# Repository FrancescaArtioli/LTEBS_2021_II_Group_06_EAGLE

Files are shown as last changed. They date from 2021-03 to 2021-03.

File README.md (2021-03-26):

# LTEBS_2021_II_Group_06_EAGLE
Authors: Artioli Francesca, Parrella Giovanni

This repository contains a complete Eagle project of a custom PCB, designed in order to ease the assessment of the performance of the PSoC-5LP microcontroller. 
In particular, the repository contains the schematic (.sch), the board (.brd) and the design-rule-check file (.dru) based on technical requirements by MDSrl. 

The PCB embeds the developement kit for PSoC-5LP (namely CY8CKIT-059_TARGET) together with sensors and additional components required to conduct the proper testing.

### Sensors (from SparkFun-Sensors.lbr) 
-	Light Sensor

	PHOTOCELLPTH - PHOTOCELL

- 	Analog Temperature Sensor

	TMP36GT9 - TO-92
  
### Libraries 

- SparkFun-Eagle-Libraries, downloaded from https://github.com/sparkfun/SparkFun-Eagle-Libraries

- CY8KIT-059.lbr, downloaded from https://github.com/dado93/Cypress-Eagle

- Group_06_Library.lbr, a custom library for TMUX1208 and TCA9546A from Texas Instruments.

### Notes on Group_06_Library.lbr
-	We have decided to design the pads for both components TMUX1208 (package QFN-16) and TCA9546A (package TSSOP-16) with a rectangular shape. 
-	Regarding package dimension of component TMUX1208 we have decided to keep the middle value between maximum and minimum dimension (1.80mmx2.60mm).
-	Regarding package dimension of component TCA9546A we have decided to keep the middle value between maximum and minimum dimension (4.4mmx5mm).
-	In both the components' footprint we have added the profile silkscreen in a way that it wouldn't provide a stop-mask error in the DRC (even if we have not considered stop mask error when running the DRC file, as suggested). 

### Notes on Group_06.sch 
-	Schematic is divided into two pages.

### Notes on Group_06.brd
-	The trace dimension was set to 10 mils for all traces of the PCB, except for those connecting to the mux which were set to 8 mils to avoid clearance errors.
-	Final board dimensions are : 60.83 mm x 72.39 mm

### Notes on Group_06.dru
-	We followed the requirements from the MDSrl.
-	The "check stop mask" option in the MISC section was not selected, as suggested.

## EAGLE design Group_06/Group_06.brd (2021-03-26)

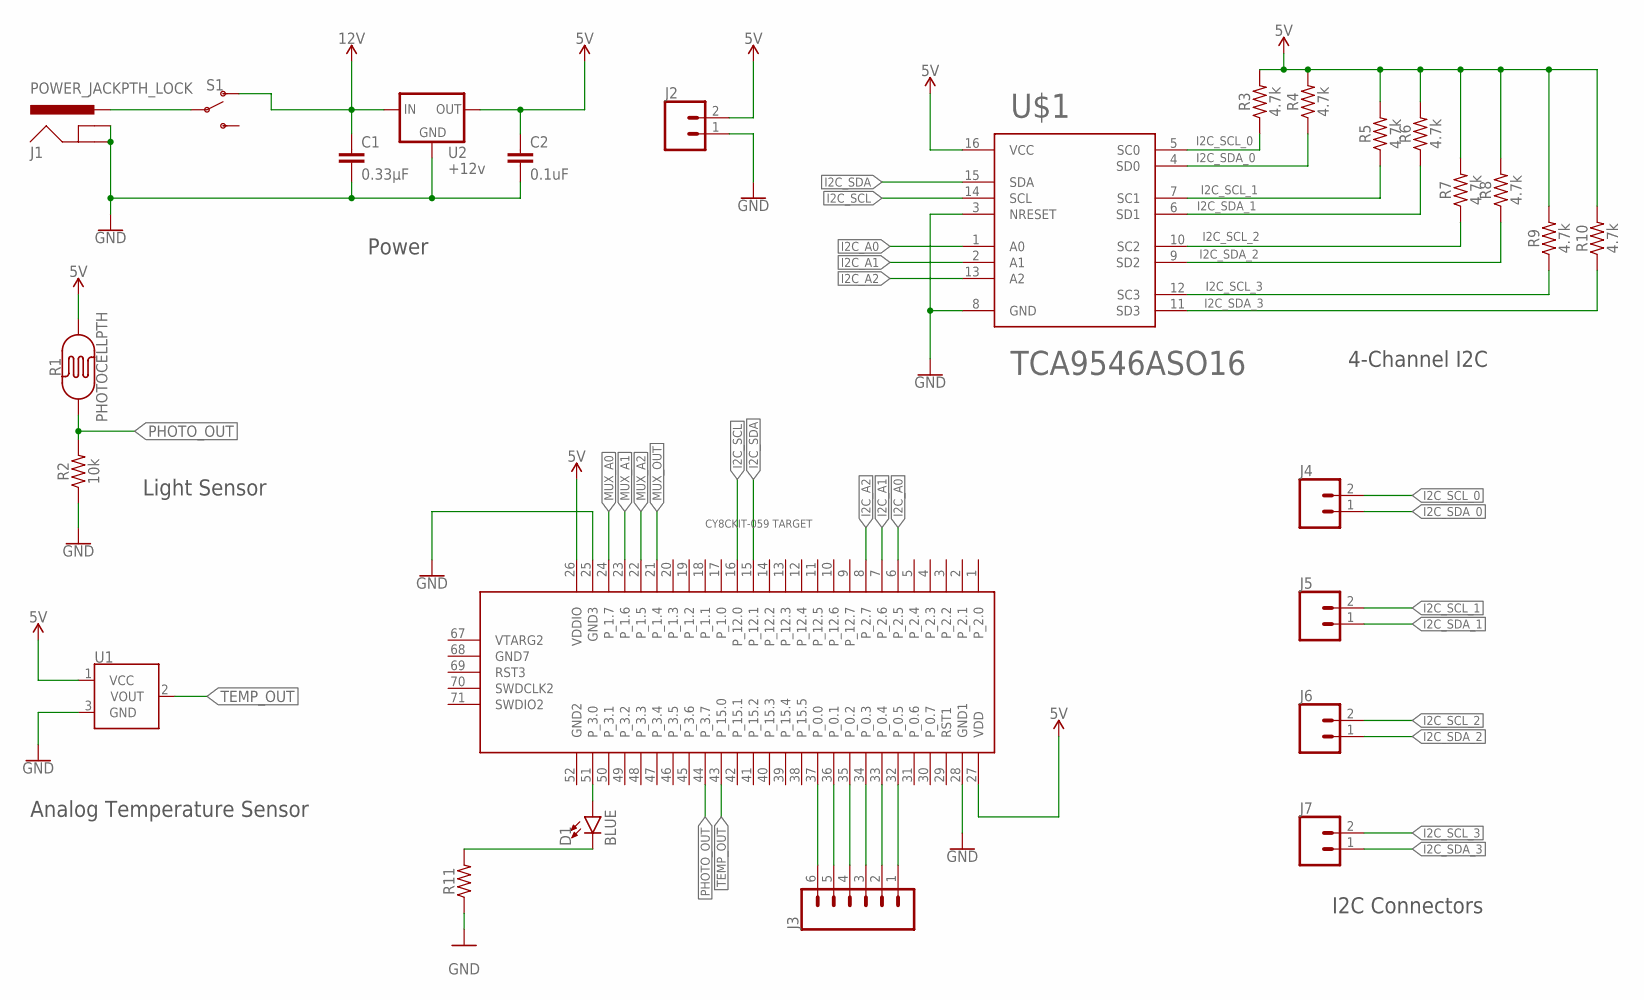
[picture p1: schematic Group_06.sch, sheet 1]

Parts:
C1: 0.33µF; 0805
C2: 0.1uF; CAP-PTH-SMALL-KIT
D1: BLUE; LED-1206
J1: POWER_JACKPTH_LOCK; POWER_JACK_PTH_LOCK
J2, J4, J5, J6, J7: CONN_02; 1X02
J3: CONN_06LOCK; 1X06_LOCK
R1: PHOTOCELLPTH; PHOTOCELL
R2: 10k; 0603
R3, R4, R5, R6, R7, R8, R9, R10: 4.7k; 0603
R11: AXIAL-0.3
S1: SWITCH-SPDT-PTH-11.6X4.0MM; SWITCH_SPDT_PTH_11.6X4.0MM
U1: TMP36GT9; TO-92
U2: +12v; TO-252
U$1: TCA9546ASO16; TSSOP-16
U$2: CY8CKIT-059_TARGET

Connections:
5V: C2.1, J2.2, R1.2, R3.2, R4.2, R5.2, R6.2, R7.2, R8.2, R9.2, R10.2, U1.1 (VCC), U2.2 (OUT), U$1.16 (VCC), U$2.26 (VDDIO), U$2.27 (VDD); also elsewhere on the board
12V: C1.1, S1.1 (O), U2.1 (IN)
GND: C1.2, C2.2, J1.GND, J1.GNDBREAK, J2.1, R2.1, R11.P$1 (1), U1.3 (GND), U2.3 (GND), U$1.3 (NRESET), U$1.8 (GND), U$2.25 (GND3), U$2.28 (GND1); also elsewhere on the board
I2C_A0: U$1.1 (A0), U$2.6 (P_2.5)
I2C_A1: U$1.2 (A1), U$2.7 (P_2.6)
I2C_A2: U$1.13 (A2), U$2.8 (P_2.7)
I2C_SCL: U$1.14 (SCL), U$2.16 (P_12.0)
I2C_SCL_0: J4.2, R3.1, U$1.5 (SC0)
I2C_SCL_1: J5.2, R5.1, U$1.7 (SC1)
I2C_SCL_2: J6.2, R7.1, U$1.10 (SC2)
I2C_SCL_3: J7.2, R9.1, U$1.12 (SC3)
I2C_SDA: U$1.15 (SDA), U$2.15 (P_12.1)
I2C_SDA_0: J4.1, R4.1, U$1.4 (SD0)
I2C_SDA_1: J5.1, R6.1, U$1.6 (SD1)
I2C_SDA_2: J6.1, R8.1, U$1.9 (SD2)
I2C_SDA_3: J7.1, R10.1, U$1.11 (SD3)
MUX_A0: U$2.24 (P_1.7); also elsewhere on the board
MUX_A1: U$2.23 (P_1.6); also elsewhere on the board
MUX_A2: U$2.22 (P_1.5); also elsewhere on the board
MUX_OUT: U$2.21 (P_1.4); also elsewhere on the board
unnamed: J1.PWR, S1.2
unnamed: D1.A, U$2.51 (P_3.0)
unnamed: D1.C, R11.P$2 (2)
unnamed: J3.6, U$2.37 (P_0.0)
unnamed: J3.5, U$2.36 (P_0.1)
unnamed: J3.4, U$2.35 (P_0.2)
unnamed: J3.3, U$2.34 (P_0.3)
unnamed: J3.2, U$2.33 (P_0.4)
unnamed: J3.1, U$2.32 (P_0.5)
PHOTO_OUT: R1.1, R2.2, U$2.44 (P_3.7)
TEMP_OUT: U1.2 (VOUT), U$2.43 (P_15.0)

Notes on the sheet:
I2C Connectors
4-Channel I2C
Power
Light Sensor
Analog Temperature Sensor

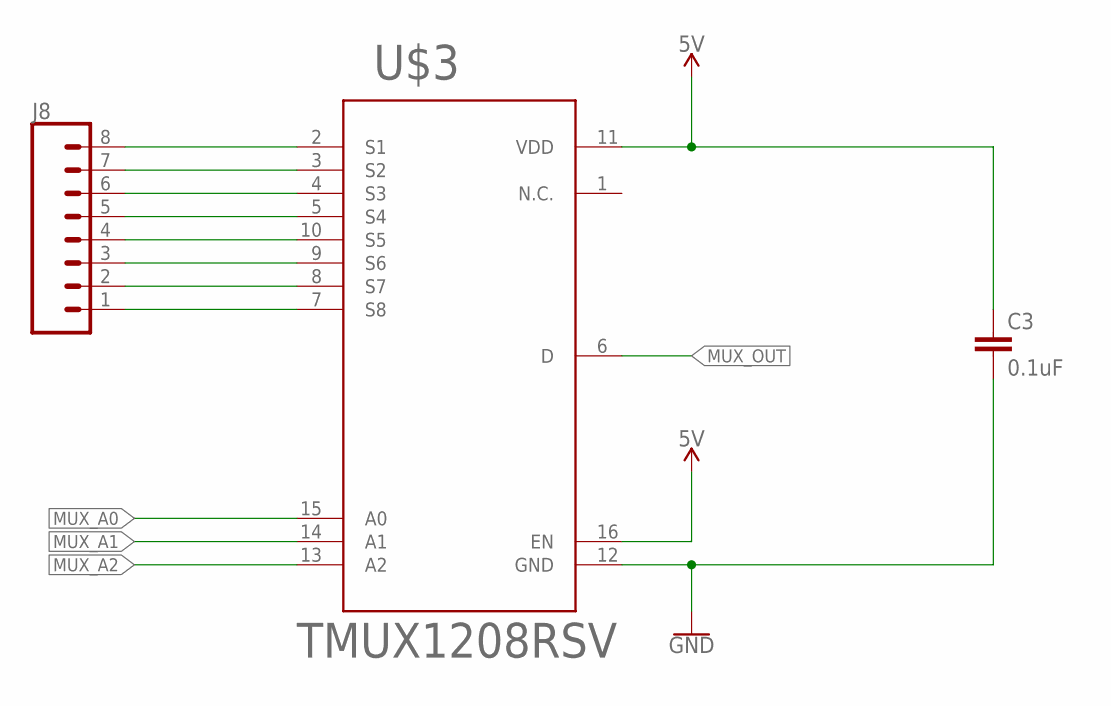
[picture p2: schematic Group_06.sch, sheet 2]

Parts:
C3: 0.1uF; CAP-PTH-SMALL-KIT
J8: CONN_08LOCK; 1X08_LOCK
U$3: TMUX1208RSV; QFN-16

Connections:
5V: C3.1, U$3.11 (VDD), U$3.16 (EN); also elsewhere on the board
GND: C3.2, U$3.12 (GND); also elsewhere on the board
MUX_A0: U$3.15 (A0); also elsewhere on the board
MUX_A1: U$3.14 (A1); also elsewhere on the board
MUX_A2: U$3.13 (A2); also elsewhere on the board
MUX_OUT: U$3.6 (D); also elsewhere on the board
unnamed: J8.8, U$3.2 (S1)
unnamed: J8.7, U$3.3 (S2)
unnamed: J8.6, U$3.4 (S3)
unnamed: J8.5, U$3.5 (S4)
unnamed: J8.4, U$3.10 (S5)
unnamed: J8.3, U$3.9 (S6)
unnamed: J8.2, U$3.8 (S7)
unnamed: J8.1, U$3.7 (S8)

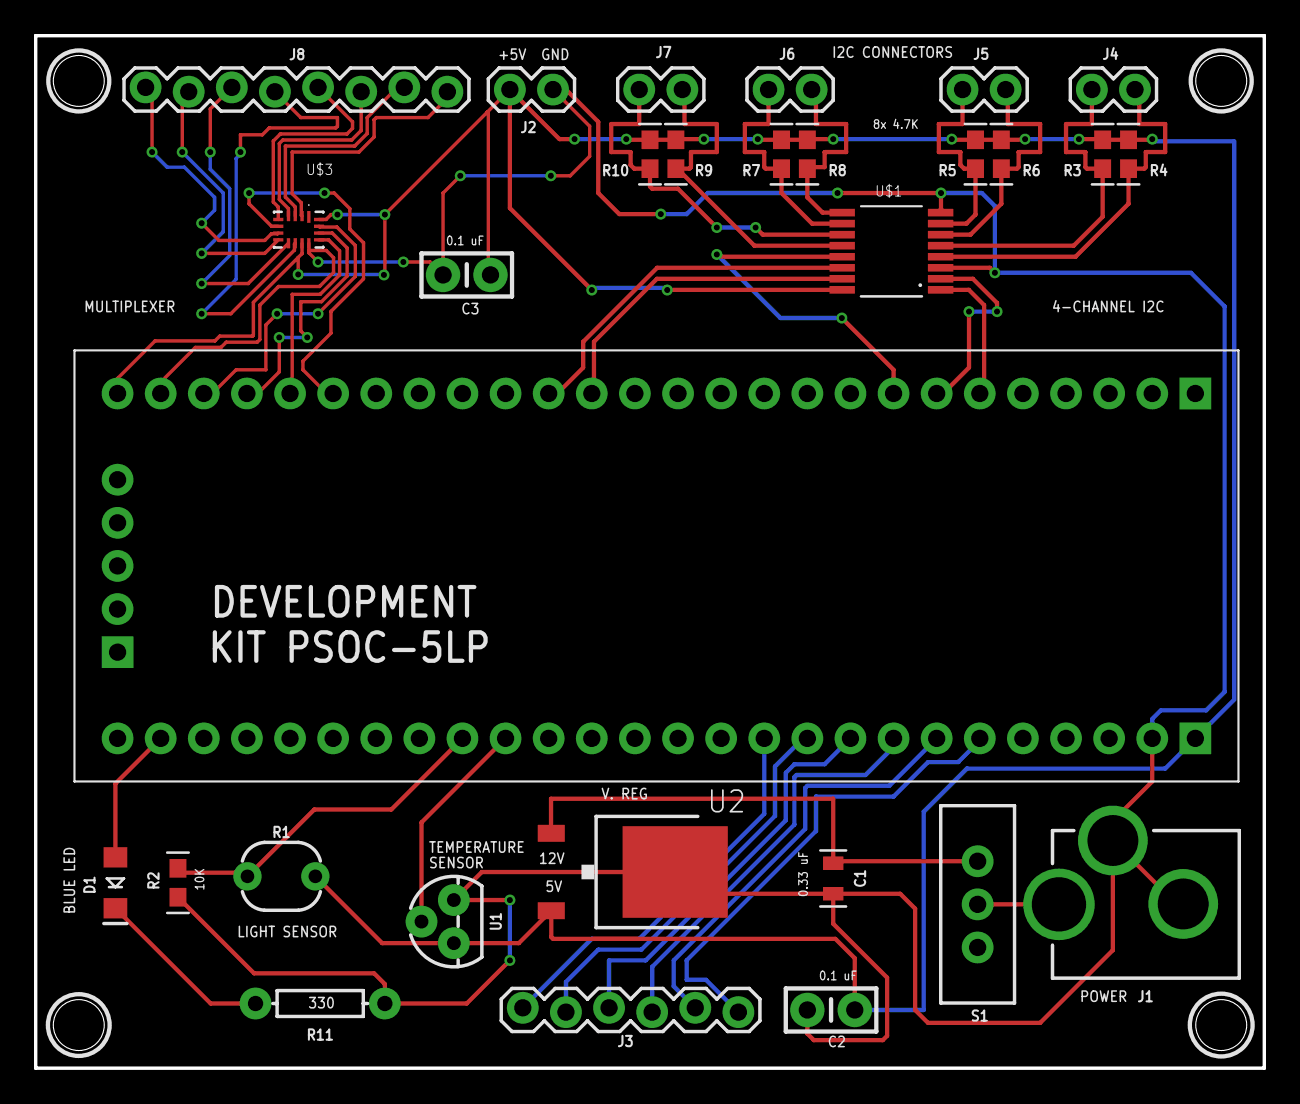
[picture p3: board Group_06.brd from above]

Board: 2 copper layers, 72.4 x 60.8 mm, 29 parts (0 on the bottom side), 39 nets.

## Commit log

2021-03-18 Sch_5components and variant name
    [Group_06.brd, Group_06.sch]
2021-03-19 I2C_Connectors and Names
    [Group_06.brd, Group_06.sch]
2021-03-19 Adding TMUX1208
    [Group_06.brd, Group_06.sch]
2021-03-19 Change microcontroller and fixing connection problem
    [Group_06.brd, Group_06.sch]
2021-03-19 first try board
    [Group_06.brd]
2021-03-20 Board Layout 1
    [Group_06.brd]
2021-03-20 Board Layout 2
    [Group_06.brd]
2021-03-20 Board Layout 3
    [Group_06.brd]
2021-03-20 Routing 1
    [Group_06.brd]
2021-03-20 Routing 2
    [Group_06.brd]
2021-03-22 Dev mux fra (#1)
    * MUX 1
    * Routing optimization and correct placing tNames
    [Group_06.brd]
2021-03-22 Silkscreen (#4)
    * update DRC file
    * Silkscreen labels and fixing stop mask interferences
    * update silkscreen and fix library problem
    [Group_06.brd]
2021-03-22 fixing power and silkscreen (#5)
    [Group_06.brd]
2021-03-23 Dev corrections (#6)
    * Change J8
    * Adding component silkscreen
    [Group_06.brd, Group_06.sch]
2021-03-23 shrinking the board (#7)
    [Group_06.brd]
2021-03-23 update board
    [Group_06.brd]
2021-03-24 correction component TCA9546A (#8)
    [Group_06.brd, Group_06.sch]
2021-03-24 Library corrections (#9)
    * Correction component TMUX1208
    * Change Layer TMUX1208
    [Group_06.brd, Group_06.sch]
2021-03-25 Update vias
    [Group_06.brd]
2021-03-25 Change MUX name position
    [Group_06.brd]
2021-03-25 DRC description and fixing silkscreen
    [Group_06.brd, Group_06.sch]
2021-03-26 GND traces and silkscreen dimensions (#10)
    [Group_06.brd, Group_06.sch]
2021-03-26 Final version
    [Group_06.brd]

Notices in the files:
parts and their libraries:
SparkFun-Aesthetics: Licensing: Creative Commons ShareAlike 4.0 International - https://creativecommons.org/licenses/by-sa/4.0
